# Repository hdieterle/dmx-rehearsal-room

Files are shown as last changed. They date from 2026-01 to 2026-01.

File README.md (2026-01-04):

# Rehearsal Room DMX Controller

A simple, standalone Arduino-based DMX lighting controller for rehearsal rooms with 20 predefined scenes.

## Features

- **Standalone Operation**: No PC required - works completely independently
- **Simple Controls**: Toggle switch for master on/off, two buttons for scene navigation
- **20 Preset Scenes**: Organized into working, mood, and show lighting categories
- **Smooth Transitions**: 1-second fade between scenes for professional look
- **Scene Memory**: Automatically remembers last scene after power cycle (EEPROM)
- **Visual Feedback**: 7-segment display shows current scene number
- **Multi-Device Support**: Controls moving heads, LED bars, and additional lighting

## Hardware Requirements

### Controller Components
- Arduino UNO R3 (or compatible)
- CTC-DRA-10-R2 DMX Shield (RS485-based)
- Adafruit 0.56" 4-Digit 7-Segment Display with I2C Backpack
- 1x Toggle Switch (Master On/Off)
- 2x Momentary Push Buttons (Scene navigation)

### DMX Fixtures
- 2x Fun Generation PicoBeam 30 Quad LED (moving heads, 13-channel mode)
- 3x Stairville LED Bar 120/4 RGB DMX (12-channel mode)
- 1x Botex MPX-4LED (dimmer channel for couch lamp)
- 1x Botex MPX-4LED (on/off channel for UV light)

## Installation

### 1. Hardware Setup

#### Arduino Pin Connections
| Component | Arduino Pin |
|---|---|
| Master On/Off Switch | D2 |
| Previous Scene Button | D3 |
| Next Scene Button | D4 |
| 7-Segment Display (I2C SDA) | A4 |
| 7-Segment Display (I2C SCL) | A5 |
| DMX Output (via Shield) | D0/D1 |

#### DMX Shield Jumper Settings (CTC-DRA-10-R2)
- **EN** (not ̅EN)
- **DE** (not Slave)
- **TX-uart** (not TX-io)

### 2. Software Installation

#### Required Libraries
Install these libraries via Arduino IDE Library Manager:
- `DMXSerial` by Matthias Hertel
- `Adafruit GFX Library`
- `Adafruit LED Backpack`
- `Wire` (included with Arduino IDE)
- `EEPROM` (included with Arduino IDE)

#### Upload the Sketch
1. Open `proberaum_dmx.ino` in Arduino IDE
2. Select **Board**: Arduino UNO
3. Select the correct **Port**
4. Click **Upload**

### 3. DMX Addressing

Configure your DMX fixtures with these start addresses:

| Fixture | DMX Start Address | Channels Used | Mode |
|---|---|---|---|
| PicoBeam #1 | 1 | 1-13 | 13ch |
| PicoBeam #2 | 14 | 14-26 | 13ch |
| LED Bar #1 | 27 | 27-38 | 12ch |
| LED Bar #2 | 39 | 39-50 | 12ch |
| LED Bar #3 | 51 | 51-62 | 12ch |
| Couch Lamp (Dimmer) | 63 | 63 | - |
| UV Light (On/Off) | 64 | 64 | - |

## Usage

### Basic Operation
1. **Power on** the Arduino controller
   - Controller automatically restores the last active scene from memory
2. Use the **Master Switch** to enable/disable all lights (displays "OFF" when disabled)
   - Turning off fades smoothly to blackout
3. Press **Next/Previous buttons** to cycle through scenes 0-19
   - Scenes fade smoothly over 1 second
   - Current scene is saved to memory automatically
4. The display shows the current scene number (e.g., "P.05" for scene 5)

### Scene Categories

#### Working Scenes (0-4)
- **0 - Blackout**: All lights off
- **1 - Work Light**: Bright white lighting for rehearsals
- **2 - Work Dim**: Dimmed white lighting
- **3 - Rehearsal Std**: Warm, cozy standard rehearsal lighting
- **4 - Rehearsal Focus**: Focused white spots with subtle ambience

#### Mood Scenes (5-9)
- **5 - Chill Blue**: Cool blue atmosphere with warm couch accent
- **6 - Warm Red**: Warm red/orange ambience
- **7 - Green Nature**: Natural green tones
- **8 - Purple Haze**: Purple/magenta mood
- **9 - UV Party**: UV blacklight with blue accents

#### Show Scenes (10-18)
- **10 - Show Split**: Red/blue color split
- **11 - Show Cyan Mag**: Cyan and magenta contrast
- **12 - Show Full White**: Maximum brightness white
- **13 - Show Strobe**: Subtle strobe effect
- **14 - Show Cross**: Crossed moving head positions
- **15 - Show Rainbow**: Rainbow colors across bars
- **16 - Show Yellow**: Bright yellow energy
- **17 - Show Wide**: Wide spread moving head positions
- **18 - Show Floor**: Downward-facing moving heads

#### Special Scenes
- **19 - Lounge**: Couch lamp only with subtle LED bar accents

## Customization

### Adding New Scenes
1. Open `proberaum_dmx.ino`
2. Increase `SCENE_COUNT` constant
3. Add a new scene entry to the `scenes[]` array
4. Upload the modified sketch

### Adjusting Pan/Tilt Values
Pan and tilt values depend on the physical mounting position of your moving heads:
- **Pan**: 0 = full left, 128 = center, 255 = full right (540° range)
- **Tilt**: 0 = up, 128 = horizontal, 255 = down (230° range)

Adjust these values in the scene definitions based on your room layout.

### Adding More DMX Fixtures
1. Update `TOTAL_CHANNELS` constant
2. Define new DMX start addresses
3. Create or extend data structures for the new fixtures
4. Modify `outputScene()` function to output to the new channels

## Technical Details

- **Memory**: Scenes stored in PROGMEM (Flash) to conserve RAM
- **Scene Transitions**: 1-second linear fade with 50 interpolation steps
  - Per-fixture fade control via boolean flags in scene definitions
  - UV light: instant snap (better visual effect)
  - Couch light: smooth fade
  - PicoBeams and LED bars: always fade
- **Scene Memory**: EEPROM-based persistence with magic number validation
- **Display Update**: Immediate when changing scenes
- **Button Debouncing**: 50ms debounce delay implemented
- **Fade Customization**: Adjustable via `FADE_DURATION_MS` and `FADE_STEPS` constants

## Known Limitations

- Fade transitions use linear interpolation (no easing curves)
- Scenes can only be modified by uploading new code (no runtime programming)
- LED Bar segment 4 has limited color control in 12-channel mode (R only, G/B missing)
- No MIDI input support
- EEPROM has ~100,000 write cycle limit (scene changes only, very long lifespan)

## Future Enhancements

Potential improvements for future versions:
- ✅ Soft fade transitions between scenes (implemented)
- ✅ EEPROM storage to remember last active scene (implemented)
- Easing curves for fades (ease-in/ease-out)
- Adjustable fade time via buttons
- Manual dimmer control via rotary encoder
- MIDI input for external control
- OLED display showing scene names instead of numbers

## Troubleshooting

### Display shows nothing
- Check I2C connections (SDA/SCL)
- Verify display address is 0x70
- Adjust brightness with `display.setBrightness()`

### No DMX output
- Verify DMX shield jumper settings
- Check DMX cable connections
- Ensure fixtures are powered and addressed correctly

### Buttons not responding
- Check pull-up resistor configuration
- Verify button wiring (should pull pin LOW when pressed)
- Test button continuity with multimeter

## Resources

- [DMXSerial Library Documentation](https://github.com/mathertel/DMXSerial)
- [PicoBeam 30 Manual](https://images.static-thomann.de/pics/atg/atgdata/document/manual/372682_c_372682_v3_en_online.pdf)
- [LED Bar 120/4 Manual](https://images.static-thomann.de/pics/atg/atgdata/document/manual/355287_c_355287_v2_de_online.pdf)
- [Open Fixture Library - PicoBeam](https://open-fixture-library.org/fun-generation/picobeam-30-quad-led)

## License

GNU General Public License v3.0 - See LICENSE file for details

## Contributing

This is a personal project for a specific rehearsal room setup. Feel free to fork and adapt it for your own needs.

## Author

Built for a basement rehearsal room with the goal of simple, reliable lighting control without requiring a computer.

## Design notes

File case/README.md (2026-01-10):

# DMX Controller Case - 3D Printing Files

Custom case design for the DMX Rehearsal Room Controller, optimized for the Prusa XL printer.

## Design Overview

**Case Style:** Two-part clamshell (top + bottom halves)
**Dimensions:** 180mm × 140mm × 50mm
**Wall Thickness:** 3mm
**Material:** Black filament recommended
**Print Settings:** 0.2mm layer height, 20% infill minimum

## Component Layout

### Bottom Half
- Arduino UNO R3 mounted internally with standoffs (no external access)
- DMX shield positioned side-by-side with Arduino (connected via jumper wires)
- 4× corner screw posts for case assembly

### Top Half - Front Panel
- USB-C panel mount connector (22mm hole, 28mm bezel)
- SS-22L05 DPDT slide switch (DMX/Programming mode selector)
- Labels: "USB", "DMX | PROG"

### Top Half - Rear Panel
- 2× Neutrik XLR-3 D-series connectors (24mm diameter, 24mm spacing)
  - Left: DMX OUT
  - Right: DMX THRU
- DC barrel jack (8mm hole) - 12V power input
- Labels: "DMX OUT", "DMX THRU", "12V DC"

### Top Half - Top Panel
- 7-segment display (50mm × 20mm rectangular cutout)
- Master toggle switch (DSQ14-R, 12mm hole)
- 2× Momentary buttons (DTQ14-S, 12mm holes)
  - PREV button
  - NEXT button
- Labels: "SCENE", "MASTER", "PREV", "NEXT"

## Files

- `dmx_controller_case.scad` - OpenSCAD source file (parametric, editable)
- `bottom_case.stl` - Bottom half STL (ready to print)
- `top_case.stl` - Top half STL (ready to print)

## How to Generate STL Files

### Method 1: Using OpenSCAD GUI (Recommended)

1. Download and install [OpenSCAD](https://openscad.org/downloads.html)
2. Open `dmx_controller_case.scad`
3. **To export bottom case:**
   - Ensure line 414 is uncommented: `bottom_case();`
   - Comment out lines 417-418 (top case)
   - Press F5 (Preview) or F6 (Render)
   - File → Export → Export as STL → Save as `bottom_case.stl`
4. **To export top case:**
   - Comment out line 414 (bottom case)
   - Uncomment lines 417-418:
     ```scad
     translate([0, case_width + 20, 0])
         top_case();
     ```
   - Press F5 (Preview) or F6 (Render)
   - File → Export → Export as STL → Save as `top_case.stl`

### Method 2: Using OpenSCAD Command Line

```bash
# Generate bottom case
openscad -o bottom_case.stl \
  -D 'RENDER_PART="bottom"' \
  dmx_controller_case.scad

# Generate top case
openscad -o top_case.stl \
  -D 'RENDER_PART="top"' \
  dmx_controller_case.scad
```

## Printing Instructions

### Prusa XL Settings
- **Filament:** Black PLA, PETG, or ABS
- **Layer Height:** 0.2mm (0.15mm for better text definition)
- **Infill:** 20% minimum (30% for more rigidity)
- **Supports:** None required (all overhangs < 45°)
- **Brim:** Optional (recommended for ABS to prevent warping)

### Print Orientation
- **Bottom case:** Print as-is (bottom facing build plate)
- **Top case:** Print upside-down (top panel facing build plate) for best surface finish on labels

### Post-Processing
- Debossed text labels can be filled with acrylic paint or paint markers for better contrast
- Use white or silver paint in debossed areas on black filament
- Wipe excess paint off surface immediately, leaving paint only in recesses

## Assembly Hardware Required

- 4× M3 × 20mm screws (corner posts, joining top and bottom halves)
- 4× M3 nuts or heat-set inserts (optional, for threaded corner posts)
- 4× M3 × 8mm screws (Arduino mounting to standoffs)
- 2× M2 × 8mm screws (SS-22L05 slide switch mounting)
- 4× M2.5 × 8mm screws (7-segment display mounting)
- Dupont jumper wires (Arduino to DMX shield connections: D0, D1, 5V, GND)

## Wiring Connections

### Arduino to DMX Shield (Side-by-Side Configuration)
| Arduino Pin | DMX Shield Pin | Wire Color Suggestion |
|---|---|---|
| D0 (RX) | D0 (RX) | Yellow |
| D1 (TX) | D1 (TX) | Orange |
| 5V | 5V | Red |
| GND | GND | Black |

### USB-C Extension Cable
- Connect internal USB-C plug to Arduino's USB-C port
- Route cable to front panel USB-C socket

### SS-22L05 Slide Switch Wiring
Wire the switch to disconnect D0/D1 during programming:
- **Position A (DMX mode):** Arduino D0/D1 connected to DMX shield
- **Position B (PROG mode):** Arduino D0/D1 disconnected from DMX shield

```
Arduino D0 ----[Switch Pole 1]---- DMX Shield D0
Arduino D1 ----[Switch Pole 2]---- DMX Shield D1
```

## Customization

The OpenSCAD file is fully parametric. You can easily adjust:
- Case dimensions (lines 9-11)
- Wall thickness (line 12)
- Component positions (lines 75-115)
- Label text (lines 361-407)
- Text depth (line 20)

After making changes, regenerate the STL files using the methods above.

## Troubleshooting

### Labels not visible
- Increase `text_depth` to 0.8mm or 1.0mm (line 20)
- Print with 0.15mm layer height for better detail
- Fill debossed text with white/silver paint

### Components don't fit
- Measure your actual components with calipers
- Update component dimensions in lines 22-73
- Regenerate STL files

### Case doesn't close properly
- Check for print warping (use brim for large flat parts)
- Verify wall thickness is exactly 3mm in slicer preview
- Sand down corner posts if too tight

## License

This case design is part of the DMX Rehearsal Room Controller project and is licensed under GPL-3.0.

## Resources

- [OpenSCAD Documentation](https://openscad.org/documentation.html)
- [Prusa XL Specifications](https://www.prusa3d.com/product/original-prusa-xl-2/)
- [Arduino UNO R3 Dimensions](https://docs.arduino.cc/hardware/uno-rev3)

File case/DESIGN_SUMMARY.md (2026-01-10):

# DMX Controller Case - Design Summary

## ✅ What's Been Created

All design files for your custom 3D-printable DMX controller case are ready!

### Files in `/case` directory:

1. **dmx_controller_case.scad** - OpenSCAD parametric design (fully editable)
2. **README.md** - Printing instructions and specifications
3. **ASSEMBLY.md** - Step-by-step assembly guide with wiring diagrams
4. **generate_stls.sh** - Helper script to generate STL files
5. **DESIGN_SUMMARY.md** - This file

## 📐 Case Specifications

| Parameter | Value |
|---|---|
| **Dimensions** | 180mm × 140mm × 50mm |
| **Wall Thickness** | 3mm |
| **Case Style** | Two-part clamshell (top + bottom) |
| **Material** | Black filament (PLA/PETG/ABS) |
| **Print Volume** | ~162,000 mm³ (fits Prusa XL easily) |
| **Estimated Print Time** | ~8-10 hours total (both halves) |
| **Assembly Hardware** | 4× M3 screws + nuts |

## 🔧 Component Layout

### Bottom Half
- Arduino UNO R3 mounted on internal standoffs
- DMX shield positioned side-by-side (connected via jumper wires)
- 4× corner screw posts for case assembly

### Top Half Panels

**Front Panel:**
- USB-C panel mount (22mm hole, 28mm bezel recess)
- SS-22L05 DPDT slide switch (DMX/PROG mode selector)
- Debossed labels: "USB", "DMX | PROG"

**Rear Panel:**
- 2× Neutrik XLR-3 connectors (24mm dia., D-series mounting)
- DC barrel jack (8mm hole, 2.1mm center-positive)
- Debossed labels: "DMX OUT", "DMX THRU", "12V DC"

**Top Panel:**
- 7-segment display (50mm × 20mm cutout)
- Master toggle switch (12mm hole)
- PREV button (12mm hole)
- NEXT button (12mm hole)
- Debossed labels: "SCENE", "MASTER", "PREV", "NEXT"

## 🖨️ How to Generate STL Files

### Option 1: OpenSCAD GUI (Easiest)

1. **Open OpenSCAD:**
   - Launch OpenSCAD from Applications folder
   - File → Open → Select `dmx_controller_case.scad`

2. **Export Bottom Case:**
   - Edit line 414: Ensure `bottom_case();` is uncommented
   - Comment out lines 417-418 (top case render)
   - Press **F6** (Render - this may take 1-2 minutes)
   - File → Export → Export as STL
   - Save as `bottom_case.stl`

3. **Export Top Case:**
   - Comment out line 414: `// bottom_case();`
   - Uncomment lines 417-418:
     ```scad
     translate([0, case_width + 20, 0])
         top_case();
     ```
   - Press **F6** (Render - this may take 1-2 minutes)
   - File → Export → Export as STL
   - Save as `top_case.stl`

### Option 2: Shell Script (If CLI works)

```bash
cd /Users/hdieterle/GitHub/dmx-rehearsal-room/case
chmod +x generate_stls.sh
./generate_stls.sh
```

*Note: OpenSCAD CLI may not work properly on macOS without Rosetta 2 or if running headless. Use GUI method if script fails.*

## 🎨 Customization Options

The design is fully parametric - you can easily adjust:

### Common Tweaks:
```scad
// Line 9-12: Case dimensions
case_length = 180;  // Make longer/shorter
case_width = 140;   // Make wider/narrower
case_height = 50;   // Make taller/shorter
wall_thickness = 3; // Make stronger/lighter

// Line 20: Label text depth
text_depth = 0.7;   // Deeper (0.8-1.0) for better visibility

// Lines 77-115: Component positions
// Adjust X/Y positions if components don't align
```

After editing, regenerate STL files.

## 🔌 Key Design Features

### ✅ Solved Problems:
1. **Arduino + Shield Side-by-Side:** Prevents XLR connector interference
2. **DMX/PROG Mode Switch:** No need to remove shield for programming
3. **USB-C Front Panel:** Easy programming access
4. **Integrated Labels:** No Dymo labels needed
5. **Desktop Stable:** No mounting holes, sits flat on table

### 🎯 Design Decisions:
- **3mm walls:** Good balance of strength and print time
- **Debossed text:** Better than embossed for black filament (paint-fillable)
- **No supports needed:** All overhangs < 45°
- **Screw posts in corners:** Easy assembly/disassembly
- **Component-specific cutouts:** Precise fit for all parts

## 📋 Next Steps

1. **Generate STL files** using OpenSCAD GUI (see above)
2. **Slice in PrusaSlicer:**
   - Import bottom_case.stl and top_case.stl
   - Use 0.2mm layer height, 20% infill
   - No supports needed
   - Consider 0.15mm layers for better label detail
3. **Print on Prusa XL** with black filament
4. **Post-process (optional):**
   - Fill debossed labels with white acrylic paint
   - Wipe excess from surface
   - Result: professional-looking white-on-black labels
5. **Assemble** following [ASSEMBLY.md](ASSEMBLY.md)

## 🛠️ If You Need Changes

The OpenSCAD file is designed for easy modifications:

### Want different labels?
→ Edit lines 361-407 in `dmx_controller_case.scad`

### Component doesn't fit?
→ Update dimensions in lines 22-73
→ Measure actual component with calipers
→ Regenerate STL

### Want different case size?
→ Change lines 9-11 (case_length, case_width, case_height)
→ Regenerate STL

### Want thicker walls?
→ Change line 12 (wall_thickness)
→ Regenerate STL

## 📚 Documentation Files

- **README.md** - Printing specs, hardware list, troubleshooting
- **ASSEMBLY.md** - Detailed assembly steps, wiring diagrams, safety notes
- **CLAUDE.md** - (in parent dir) Technical project documentation

## 🎉 Design Complete!

All files are ready. You now have:
- ✅ Parametric OpenSCAD design
- ✅ Component specifications
- ✅ Printing instructions
- ✅ Assembly guide
- ✅ Wiring diagrams
- ✅ Helper scripts

**Total Design Time:** ~2 hours
**Estimated Print Time:** ~8-10 hours
**Estimated Assembly Time:** ~2-3 hours

---

## 💡 Tips

1. **First print?** Start with bottom case only to test fit
2. **Labels hard to read?** Increase text_depth to 0.8mm or paint them white
3. **Case won't close?** Check for print warping, sand corner posts if needed
4. **Components loose?** Add small pieces of foam tape for snug fit
5. **Want ventilation?** Add small holes in bottom case (edit line ~125)

## 📞 Support

If you need design modifications or have questions:
- Check [README.md](README.md) for printing FAQs
- Check [ASSEMBLY.md](ASSEMBLY.md) for assembly help
- Review OpenSCAD comments for parameter explanations
- Test fit components before final assembly

**Enjoy your custom DMX controller case!** 🎵💡

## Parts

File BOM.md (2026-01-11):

# Bill of Materials (BOM)

Complete parts list for building the DMX Rehearsal Room Controller.

## Electronics

| Qty | Component | Description | Notes |
|-----|---|---|---|
| 1 | Arduino UNO R3 | Microcontroller board | Official or compatible clone |
| 1 | CTC-DRA-10-R2 DMX Shield | RS485-based DMX interface | - |
| 1 | Adafruit 0.56" 4-Digit 7-Segment Display | Yellow, with I2C backpack | Part #: 878 or 879 |
| 1 | USB-C Panel Mount Extension Cable | 22mm hole, 28mm bezel | Male-to-female, ~30cm cable length |
| 1 | SS-22L05 DPDT Slide Switch | DMX/Programming mode selector | 6-pin, through-hole mounting |
| 1 | DSQ14-R Toggle Switch | Master On/Off, 12mm mounting hole | SPST or SPDT |
| 2 | DTQ14-S Momentary Push Buttons | Preset Prev/Next, 12mm mounting hole | Normally open (NO) |
| 2 | Neutrik XLR-3 D-Series Panel Mount | 24mm mounting hole | NC3FD-LX (female) or similar |
| 1 | DC Barrel Jack Panel Mount | 2.1mm center-positive, 8mm mounting hole | 9-12V input |
| 1 | 12V DC Power Supply | Center-positive, 2.1mm barrel plug | Minimum 1A, recommend 2A+ |
| 1 | USB-A to USB-B Cable | For Arduino programming | ~1-2m length recommended |

## Wiring & Connectors

| Qty | Component | Description | Notes |
|-----|---|---|---|
| 1 | Dupont Jumper Wire Set | Male-to-female, 10-15cm length | For Arduino-to-shield connections |
| 1m | 22-24 AWG Stranded Wire | Assorted colors | For switch wiring |
| 1m | Heat Shrink Tubing | Assorted sizes | For wire insulation |

## Hardware (Case Assembly)

| Qty | Component | Description | Notes |
|-----|---|---|---|
| 4 | M3 × 20mm Screws | Corner posts (case assembly) | Phillips or socket head |
| 4 | M3 Nuts | For corner posts | Or use heat-set inserts |
| 4 | M3 × 8mm Screws | Arduino mounting | Phillips |
| 2 | M2 × 8mm Screws | Slide switch mounting | Phillips |
| 2 | M2 Nuts | Slide switch mounting | - |
| 4 | M2.5 × 8mm Screws | Display mounting | Phillips |

## 3D Printing Materials

| Qty | Component | Description | Notes |
|-----|---|---|---|
| ~200g | Black Filament | PLA, PETG, or ABS | For bottom case |
| ~100g | Black Filament | PLA, PETG, or ABS | For top case (lid) |

**Print Settings:**
- Layer height: 0.2mm (or 0.15mm for better label detail)
- Infill: 20% minimum (30% recommended)
- Supports: None required
- Estimated print time: 8-10 hours total

## Optional Components

| Qty | Component | Description | Notes |
|-----|---|---|---|
| 1 | White Acrylic Paint | For filling debossed labels | Optional, improves label visibility |
| 4 | M3 Heat-Set Inserts | Alternative to M3 nuts | For cleaner assembly |
| 1 | Cable Management Kit | Zip ties, adhesive mounts | For internal wire routing |

## DMX Fixtures (Not Included)

The controller is designed for the following DMX fixtures (not included in this BOM):

| Qty | Fixture | Start Address | Channels |
|-----|---|---|---|
| 2 | Fun Generation PicoBeam 30 Quad LED | 1, 14 | 13ch each (26ch total) |
| 3 | Stairville LED Bar 120/4 RGB DMX | 27, 39, 51 | 12ch each (36ch total) |
| 1 | Botex MPX-4LED (Channel 1) | 63 | 1ch (dimmer) |
| 1 | Botex MPX-4LED (Channel 2) | 64 | 1ch (on/off) |

**Total DMX Channels Used:** 64

## Tools Required

### Soldering
- Soldering iron (for switch wiring)
- Solder (60/40 rosin core)
- Wire strippers
- Flush cutters
- Helping hands or PCB holder

### Assembly
- Phillips screwdrivers (various sizes)
- Small flathead screwdriver
- Multimeter (for continuity testing)
- Calipers (optional, for measuring components)

### 3D Printing
- 3D printer (Prusa XL or similar, min. 180×140×60mm build volume)
- Slicer software (PrusaSlicer recommended)

### Optional
- Heat-set insert tool (soldering iron with tip works)
- Deburring tool (for cleaning print edges)
- Small paintbrush (for filling labels)

## Estimated Total Cost

| Category | Estimated Cost (EUR) |
|---|---|
| Electronics | €80-120 |
| Wiring & Connectors | €10-15 |
| Hardware | €5-10 |
| 3D Printing Materials | €10-15 |
| **Total** | **€105-160** |

*Prices are approximate and may vary by supplier and region.*

## Recommended Suppliers

### Europe
- **Electronics:** Reichelt, Conrad, Mouser, DigiKey
- **DMX Components:** Thomann, Musicstore
- **Hardware:** Würth, local hardware store
- **3D Printing:** Prusa3D filament, local suppliers

### General
- **Arduino/Electronics:** Amazon, AliExpress (clones)
- **Adafruit Products:** Adafruit.com, authorized distributors
- **Neutrik Connectors:** Thomann, official Neutrik distributors

## Notes

1. **Arduino Clones:** Compatible Arduino UNO R3 clones work fine and are significantly cheaper than official boards.

2. **Switch Compatibility:** The DSQ14-R and DTQ14-S switch part numbers may vary by supplier. Look for 12mm mounting hole toggle/momentary switches.

3. **Power Supply:** Ensure the power supply is center-positive and rated for at least 1A. The Arduino draws ~50-100mA, plus any connected fixtures draw power from their own supplies.

4. **XLR Connectors:** The Neutrik D-series (NC3FD-LX) are panel-mount female XLR connectors. The "D" designation refers to the D-shaped mounting flange.

5. **Filament Color:** Black filament is recommended for debossed labels. The labels can optionally be filled with white acrylic paint for better contrast.

6. **Heat-Set Inserts:** If using heat-set inserts instead of M3 nuts, use M3×5.7mm (OD) inserts designed for 3D printing.

## Assembly Instructions

Refer to [case/ASSEMBLY.md](case/ASSEMBLY.md) for detailed step-by-step assembly instructions.

## Design Files

- OpenSCAD source: [case/dmx_controller_case.scad](case/dmx_controller_case.scad)
- Arduino sketch: [proberaum_dmx/proberaum_dmx.ino](proberaum_dmx/proberaum_dmx.ino)
- Printing guide: [case/README.md](case/README.md)

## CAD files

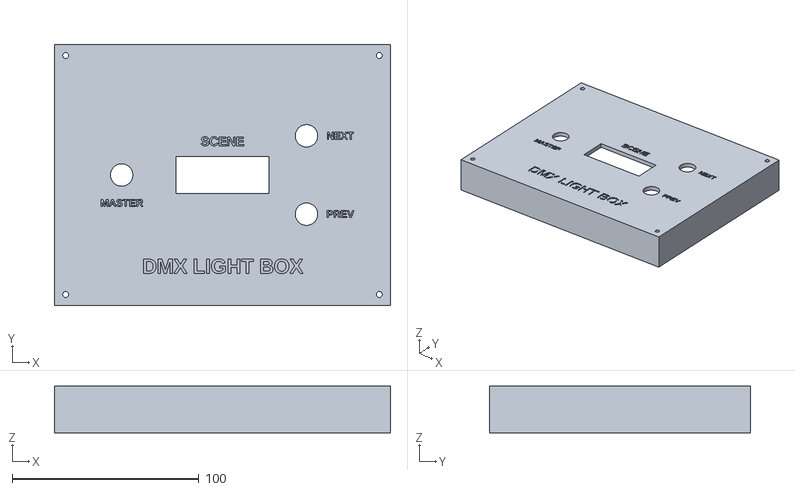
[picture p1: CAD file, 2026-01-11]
case/dmx_controller_case_top.stl
180.0 x 140.0 x 25.0

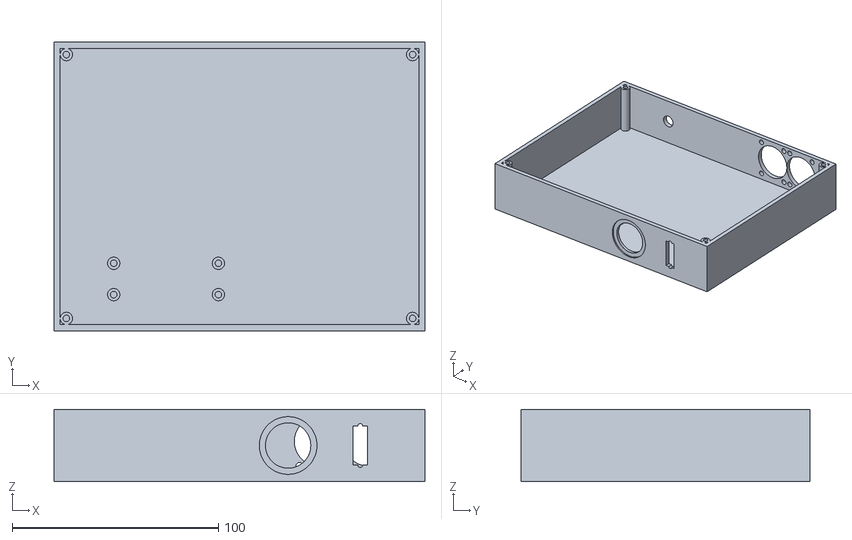
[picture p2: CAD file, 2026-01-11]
case/dmx_controller_case_bottom.stl
180.0 x 140.0 x 35.0

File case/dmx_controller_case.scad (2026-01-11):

// DMX Rehearsal Room Controller Case
// Two-part clamshell design for Prusa XL
// All dimensions in millimeters

// ========== GLOBAL PARAMETERS ==========
$fn = 60; // Circle resolution (higher = smoother, slower render)

// Case dimensions
case_length = 180;  // X direction (front to back)
case_width = 140;   // Y direction (left to right)
case_height = 60;   // Z direction (total height - increased for better proportions)
case_bottom_height = 35;  // Height of bottom case (contains all connectors)
case_top_height = 25;     // Height of top case (lid)
wall_thickness = 3; // Wall thickness

// Screw posts for case assembly
screw_post_diameter = 6;
screw_hole_diameter = 3.2; // M3 screw clearance
screw_post_count = 4; // Corner posts

// Label text depth
text_depth = 0.7; // Debossed text for black filament

// ========== COMPONENT DIMENSIONS ==========

// Arduino UNO R3
arduino_length = 68.6;
arduino_width = 53.3;
arduino_hole_spacing_length = 50.8;
arduino_hole_spacing_width = 15.2;
arduino_hole_offset_x = 13.97;
arduino_hole_offset_y = 2.54;
arduino_mount_hole = 3.2; // M3 clearance
arduino_standoff_height = 8; // Height above case bottom

// DMX Shield (approximate based on XLR positions)
shield_length = 70;
shield_width = 60;
shield_standoff_height = 8;

// XLR Connectors (Neutrik D-series)
xlr_diameter = 24;
xlr_spacing = 24; // Center to center
xlr_screw_spacing = 19; // Horizontal screw spacing
xlr_screw_vertical = 24; // Vertical position from center
xlr_screw_hole = 3.5; // Mounting screw size

// USB-C Panel Mount
usbc_hole_diameter = 22;
usbc_bezel_diameter = 28;
usbc_bezel_depth = 1.5;

// SS-22L05 DPDT Slide Switch
slide_switch_width = 19;
slide_switch_height = 6.9;
slide_switch_slot_length = 5;
slide_switch_slot_width = 2.5;
slide_switch_screw_spacing = 19; // Horizontal M2 screw spacing
slide_switch_screw_hole = 2.3; // M2 clearance

// Toggle Switch (DSQ14-R)
toggle_hole_diameter = 12;

// Momentary Buttons (DTQ14-S)
button_hole_diameter = 12;

// 7-Segment Display (Adafruit 0.56" 4-digit)
display_width = 50;
display_height = 20;
display_screw_spacing_x = 45; // Approximate
display_screw_spacing_y = 15; // Approximate
display_screw_hole = 2.5; // M2.5 or small screw

// DC Barrel Jack
dc_jack_hole_diameter = 8;

// ========== COMPONENT POSITIONS ==========

// Arduino position (bottom left area)
arduino_pos_x = 15;
arduino_pos_y = 15;

// DMX Shield position (bottom right area, side-by-side with Arduino)
shield_pos_x = arduino_pos_x + arduino_length + 20; // 20mm gap for wiring
shield_pos_y = 15;

// Front panel components (front = Y=0 end)
// USB and switch positioned above DMX shield (right side)
usbc_pos_x = shield_pos_x + 10;  // Positioned above shield (~113mm from left)
usbc_pos_y = 0;
usbc_pos_z = case_bottom_height / 2;  // Centered in bottom case wall (17.5mm)

slide_switch_pos_x = shield_pos_x + 45;  // Positioned right of USB (~148mm from left)
slide_switch_pos_y = 0;
slide_switch_pos_z = case_bottom_height / 2;  // Centered in bottom case wall (17.5mm)

// Rear panel components (rear = Y=case_width end)
// XLRs positioned above the DMX shield (right side of case)
xlr_pos_x = shield_pos_x + 25;  // Positioned above shield (~129mm from left)
xlr_pos_y = case_width;
xlr_pos_z = case_bottom_height / 2 + 2;  // Raised 2mm higher (19.5mm) for shield solder bumps
xlr_left_offset_x = 0;
xlr_right_offset_x = xlr_spacing;

dc_jack_pos_x = arduino_pos_x + 25;  // Positioned above Arduino (~40mm from left)
dc_jack_pos_y = case_width;
dc_jack_pos_z = case_bottom_height / 2 + 2;  // Raised 2mm higher (19.5mm) to match XLRs

// Top panel components
display_pos_x = case_length * 0.5;
display_pos_y = case_width * 0.5;

toggle_pos_x = case_length * 0.2;
toggle_pos_y = case_width * 0.5;

button_prev_pos_x = case_length * 0.75;
button_prev_pos_y = case_width * 0.35;

button_next_pos_x = case_length * 0.75;
button_next_pos_y = case_width * 0.65;

// ========== MODULES ==========

// Bottom case half
module bottom_case() {
    difference() {
        // Main shell
        union() {
            // Bottom plate
            cube([case_length, case_width, wall_thickness]);

            // Walls (bottom case)
            translate([0, 0, 0])
                cube([wall_thickness, case_width, case_bottom_height]);
            translate([case_length - wall_thickness, 0, 0])
                cube([wall_thickness, case_width, case_bottom_height]);
            translate([0, 0, 0])
                cube([case_length, wall_thickness, case_bottom_height]);
            translate([0, case_width - wall_thickness, 0])
                cube([case_length, wall_thickness, case_bottom_height]);

            // Corner screw posts
            create_corner_posts();

            // Arduino mounting posts
            create_arduino_posts();

            // DMX Shield mounting posts (will screw into XLR connectors)
            // (Not needed as XLRs mount to rear panel)
        }

        // Screw holes in corner posts (threaded from top)
        corner_post_positions() {
            translate([0, 0, -1])
                cylinder(h=case_bottom_height + 2, d=screw_hole_diameter);
        }

        // Front panel cutouts (Y=0 wall) - all in bottom case
        translate([usbc_pos_x, usbc_pos_y, usbc_pos_z])
            rotate([90, 0, 0])
                usbc_cutout();

        translate([slide_switch_pos_x, slide_switch_pos_y, slide_switch_pos_z])
            rotate([90, 0, 0])
                slide_switch_cutout();

        // Rear panel cutouts (Y=case_width wall) - bottom half
        translate([xlr_pos_x + xlr_left_offset_x, xlr_pos_y, xlr_pos_z])
            rotate([90, 0, 0])
                xlr_cutout();

        translate([xlr_pos_x + xlr_right_offset_x, xlr_pos_y, xlr_pos_z])
            rotate([90, 0, 0])
                xlr_cutout();

        translate([dc_jack_pos_x, dc_jack_pos_y, dc_jack_pos_z])
            rotate([90, 0, 0])
                translate([0, 0, -wall_thickness - 1])
                    cylinder(h=wall_thickness + 4, d=dc_jack_hole_diameter);

        // Front/Rear panel labels (debossed text on bottom case)
        labels_bottom_case();
    }
}

// Top case half (lid)
module top_case() {
    difference() {
        // Main shell
        union() {
            // Top plate
            translate([0, 0, case_top_height - wall_thickness])
                cube([case_length, case_width, wall_thickness]);

            // Walls (top case - shorter, acts as lid)
            translate([0, 0, 0])
                cube([wall_thickness, case_width, case_top_height]);
            translate([case_length - wall_thickness, 0, 0])
                cube([wall_thickness, case_width, case_top_height]);
            translate([0, 0, 0])
                cube([case_length, wall_thickness, case_top_height]);
            translate([0, case_width - wall_thickness, 0])
                cube([case_length, wall_thickness, case_top_height]);

            // Corner screw posts (top case)
            create_corner_posts_top();
        }

        // Top panel cutouts
        translate([display_pos_x, display_pos_y, case_top_height - wall_thickness - 1])
            display_cutout();

        translate([toggle_pos_x, toggle_pos_y, case_top_height - wall_thickness - 1])
            cylinder(h=wall_thickness + 2, d=toggle_hole_diameter);

        translate([button_prev_pos_x, button_prev_pos_y, case_top_height - wall_thickness - 1])
            cylinder(h=wall_thickness + 2, d=button_hole_diameter);

        translate([button_next_pos_x, button_next_pos_y, case_top_height - wall_thickness - 1])
            cylinder(h=wall_thickness + 2, d=button_hole_diameter);

        // Screw holes in corner posts (clearance from bottom)
        corner_post_positions() {
            translate([0, 0, -1])
                cylinder(h=case_top_height + 2, d=screw_hole_diameter);
        }

        // Labels (debossed text)
        labels();
    }
}

// Corner screw post positions and creation
module corner_post_positions() {
    offset = screw_post_diameter / 2 + wall_thickness;

    for (pos = [
        [offset, offset, wall_thickness],
        [case_length - offset, offset, wall_thickness],
        [offset, case_width - offset, wall_thickness],
        [case_length - offset, case_width - offset, wall_thickness]
    ]) {
        translate(pos)
            children();
    }
}

// Create corner screw posts for bottom case
module create_corner_posts_bottom() {
    corner_post_positions()
        cylinder(h=case_bottom_height - wall_thickness, d=screw_post_diameter);
}

// Create corner screw posts for top case
module create_corner_posts_top() {
    corner_post_positions()
        cylinder(h=case_top_height - wall_thickness, d=screw_post_diameter);
}

// Compatibility wrapper - defaults to bottom
module create_corner_posts() {
    create_corner_posts_bottom();
}
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

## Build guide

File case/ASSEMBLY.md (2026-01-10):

# DMX Controller Case - Assembly Guide

Step-by-step instructions for assembling your custom DMX controller case.

## Required Components

### Electronics
- [x] Arduino UNO R3
- [x] CTC-DRA-10-R2 DMX Shield
- [x] Adafruit 0.56" 4-Digit 7-Segment Display (yellow, with I2C backpack)
- [x] USB-C panel mount extension cable
- [x] SS-22L05 DPDT slide switch (programming mode selector)
- [x] DSQ14-R toggle switch (Master On/Off)
- [x] 2× DTQ14-S momentary push buttons (Preset Prev/Next)
- [x] 2× Neutrik XLR-3 D-series panel mount connectors
- [x] DC barrel jack panel mount (2.1mm, 8mm mounting hole)
- [x] Dupont jumper wires (male-to-female, 10-15cm length)

### Hardware
- [x] 4× M3 × 20mm screws (case assembly)
- [x] 4× M3 nuts or heat-set inserts
- [x] 4× M3 × 8mm screws (Arduino mounting)
- [x] 2× M2 × 8mm screws + nuts (slide switch)
- [x] 4× M2.5 × 8mm screws (display mounting)
- [x] Wire (22-24 AWG) for switch wiring
- [x] Heat shrink tubing

### Tools
- Soldering iron (for switch wiring)
- Wire strippers
- Screwdriver set (Phillips, flathead)
- Flush cutters
- Multimeter (for continuity testing)
- Heat-set insert tool (optional, if using inserts)

## Pre-Assembly: Print the Case

1. **Print both halves:**
   - Open `dmx_controller_case.scad` in OpenSCAD
   - Follow instructions in `README.md` to export `bottom_case.stl` and `top_case.stl`
   - Print on Prusa XL with black filament
   - Settings: 0.2mm layer height, 20%+ infill

2. **Post-process (optional):**
   - Fill debossed labels with white acrylic paint
   - Let dry, then wipe excess from surface
   - Result: white text on black background

## Step 1: Mount Arduino to Bottom Case

1. Place Arduino UNO in bottom case (left side, near front-left corner)
2. Align Arduino mounting holes with standoffs
3. Insert 4× M3 × 8mm screws through Arduino holes into standoffs
4. Tighten screws (don't overtighten, PCB can crack)

**Position:** Arduino should be ~15mm from left wall, ~15mm from front wall

## Step 2: Wire the SS-22L05 Slide Switch (DMX/PROG Mode Selector)

This switch disconnects D0/D1 from the DMX shield during programming.

### Wiring Diagram

```
                       SS-22L05 DPDT Slide Switch
                       (View from solder side)

    Common Pole 1 ----o   o---- NO Contact 1
    Common Pole 2 ----o   o---- NO Contact 2

DMX Mode (Position A):
  Arduino D0 → Common Pole 1 → NO Contact 1 → DMX Shield D0
  Arduino D1 → Common Pole 2 → NO Contact 2 → DMX Shield D1

PROG Mode (Position B):
  Arduino D0 → Common Pole 1 (disconnected)
  Arduino D1 → Common Pole 2 (disconnected)
  DMX Shield D0/D1 → floating (disconnected)
```

### Steps

1. **Cut 4 wires** (~8-10cm each):
   - 2× Orange (for D1 connections)
   - 2× Yellow (for D0 connections)

2. **Solder to switch:**
   - Common Pole 1: Yellow wire to Arduino D0
   - Common Pole 2: Orange wire to Arduino D1
   - NO Contact 1: Yellow wire to DMX Shield D0
   - NO Contact 2: Orange wire to DMX Shield D1

3. **Add heat shrink** to each solder joint

4. **Test with multimeter:**
   - Position A (DMX): Continuity between Arduino D0/D1 and Shield D0/D1
   - Position B (PROG): No continuity

## Step 3: Position DMX Shield

1. Place DMX shield in bottom case (right side, side-by-side with Arduino)
2. Shield will be secured by XLR connectors mounting to rear panel
3. **Do not stack** shield on Arduino (causes XLR connector clearance issues)

**Position:** Shield should be ~103mm from left wall (~20mm gap after Arduino), ~15mm from front wall

## Step 4: Wire Arduino to DMX Shield

Use Dupont jumper wires to connect (remember: D0/D1 go through the slide switch):

| Connection | Wire | Notes |
|---|---|---|
| Arduino 5V → Shield 5V | Red jumper | Direct connection |
| Arduino GND → Shield GND | Black jumper | Direct connection |
| Arduino D0 → Switch Pole 1 | Yellow (from Step 2) | Via slide switch |
| Switch NO1 → Shield D0 | Yellow (from Step 2) | Via slide switch |
| Arduino D1 → Switch Pole 2 | Orange (from Step 2) | Via slide switch |
| Switch NO2 → Shield D1 | Orange (from Step 2) | Via slide switch |

## Step 5: Mount Rear Panel Components

### XLR Connectors (2× Neutrik D-series)
1. Insert left XLR through rear panel hole (labeled "DMX OUT")
2. Insert right XLR through rear panel hole (labeled "DMX THRU")
3. Secure each with 4× mounting screws (included with Neutrik connectors)
4. **This secures the DMX shield in place**

### DC Barrel Jack
1. Insert DC jack through rear panel 8mm hole
2. Secure with included nut or mounting screws
3. Wire DC jack to Arduino Vin and GND:
   - Center pin (+) → Arduino Vin
   - Outer sleeve (-) → Arduino GND

## Step 6: Mount Front Panel Components

### USB-C Panel Mount
1. Feed USB-C extension cable through case from inside
2. Insert panel mount socket through front panel 22mm hole
3. Socket bezel should sit flush in recess
4. Connect internal USB-C plug to Arduino's USB-C port

### SS-22L05 Slide Switch
1. Insert switch through front panel rectangular cutout
2. Align mounting holes
3. Secure with 2× M2 × 8mm screws and nuts from inside
4. Verify slider moves freely between DMX and PROG positions
5. Label positions with marker if needed

## Step 7: Mount Top Panel Components

### 7-Segment Display
1. Insert display through 50mm × 20mm rectangular cutout from inside
2. Display should be visible from top, PCB on inside
3. Secure with 4× M2.5 × 8mm screws around display corners
4. Connect display I2C cable to Arduino:
   - VCC → Arduino 5V
   - GND → Arduino GND
   - SDA → Arduino A4
   - SCL → Arduino A5

### Master Toggle Switch (DSQ14-R)
1. Insert switch through 12mm hole (labeled "MASTER")
2. Secure with included nut
3. Wire switch to Arduino D2:
   - One terminal → Arduino D2
   - Other terminal → Arduino GND

### Momentary Buttons (2× DTQ14-S)
1. **PREV button:** Insert through left 12mm hole (labeled "PREV")
2. **NEXT button:** Insert through right 12mm hole (labeled "NEXT")
3. Secure each with included nuts
4. Wire buttons to Arduino:
   - PREV: One terminal → Arduino D3, other → GND
   - NEXT: One terminal → Arduino D4, other → GND

## Step 8: Final Assembly

1. **Test before closing:**
   - Set slide switch to PROG position
   - Connect USB cable to front panel USB-C socket
   - Upload sketch from [proberaum_dmx.ino](../proberaum_dmx/proberaum_dmx.ino)
   - Verify upload succeeds
   - Set slide switch to DMX position
   - Power via DC jack (9-12V)
   - Test all buttons, display, and master switch

2. **Close the case:**
   - Carefully align top and bottom halves
   - Ensure no wires are pinched
   - Insert 4× M3 × 20mm screws through corner posts
   - Tighten screws evenly (diagonal pattern)

3. **Final check:**
   - All labels visible and readable
   - Slide switch moves freely
   - Display shows scene number
   - Buttons respond correctly
   - DMX output working (test with DMX fixture)

## Wiring Color Code Reference

| Connection | Recommended Wire Color |
|---|---|
| +5V / VCC  | Red |
| GND | Black |
| D0 (RX) | Yellow |
| D1 (TX) | Orange |
| D2 (Master)| Blue |
| D3 (Prev)  | Green |
| D4 (Next)  | Purple |
| A4 (SDA) | White |
| A5 (SCL) | Brown |

## Troubleshooting

### Arduino won't program
- **Check:** Slide switch in PROG position?
- **Check:** USB-C cable properly connected?
- **Check:** Arduino visible in Arduino IDE (Tools → Port)?

### Display not working
- **Check:** I2C address (default 0x70, check code)
- **Check:** SDA/SCL connections (A4/A5)
- **Check:** Display power (5V/GND)

### Buttons not responding
- **Check:** Button wiring (one side to Arduino pin, other to GND)
- **Check:** Code pullup resistors enabled (`pinMode(pin, INPUT_PULLUP)`)

### DMX not outputting
- **Check:** Slide switch in DMX position
- **Check:** D0/D1 wired correctly through switch
- **Check:** Shield jumpers set correctly (EN, DE, TX-uart)

### Case won't close
- **Check:** Wires not bunched up or pinched
- **Check:** Arduino seated flat on standoffs
- **Check:** No component interference

## Maintenance

- **Switch cleaning:** Spray contact cleaner into slide switch yearly
- **Display brightness:** Adjustable in code (`display.setBrightness(15)`)
- **Firmware updates:** Set switch to PROG, connect USB, upload new code

## Safety Notes

⚠️ **Important:**
- Always disconnect power before opening case
- Use 9-12V DC power only (center positive)
- Don't exceed 12V (Arduino damage risk)
- Ensure XLR connectors are properly wired (pin 1=GND, 2=Data-, 3=Data+)
- Keep case dry (not waterproof)

## Done!

Your DMX controller is now assembled and ready for use in the rehearsal room. Enjoy the smooth scene transitions! 🎵💡

---

**Next Steps:**
- Read [README.md](../README.md) for usage instructions
- Explore scene customization in [proberaum_dmx.ino](../proberaum_dmx/proberaum_dmx.ino)
- Check [CLAUDE.md](../CLAUDE.md) for technical details

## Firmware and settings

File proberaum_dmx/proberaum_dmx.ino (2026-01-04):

/*
 * Rehearsal Room DMX Controller
 *
 * Hardware:
 * - Arduino UNO
 * - CTC-DRA-10-R2 DMX Shield
 * - Toggle switch on Pin 2 (Master On/Off)
 * - Button on Pin 3 (Previous preset)
 * - Button on Pin 4 (Next preset)
 *
 * DMX Devices:
 * - Channel 1-13:  PicoBeam 1 (13ch mode)
 * - Channel 14-26: PicoBeam 2 (13ch mode)
 * - Channel 27-38: LED Bar 1 (12ch mode)
 * - Channel 39-50: LED Bar 2 (12ch mode)
 * - Channel 51-62: LED Bar 3 (12ch mode)
 * - Channel 63:    Botex Dimmer (Couch hanging lamp)
 * - Channel 64:    Botex UV light (On/Off)
 *
 * Jumper Settings CTC-DRA-10-R2:
 * - EN (not ̅EN)
 * - DE (not Slave)
 * - TX-uart (not TX-io)
 */

#include <DMXSerial.h>
#include <Wire.h>
#include <Adafruit_GFX.h>
#include <Adafruit_LEDBackpack.h>
#include <EEPROM.h>

Adafruit_7segment display = Adafruit_7segment();

// === PIN DEFINITIONS ===
const byte PIN_MASTER = 2;    // Toggle switch Master On/Off
const byte PIN_PREV = 3;      // Button previous preset
const byte PIN_NEXT = 4;      // Button next preset

// === DMX ADDRESSES ===
const byte PICO1_START = 1;
const byte PICO2_START = 14;
const byte BAR1_START = 27;
const byte BAR2_START = 39;
const byte BAR3_START = 51;
const byte BOTEX_COUCH = 63;
const byte BOTEX_UV = 64;

const byte TOTAL_CHANNELS = 64;

// === FADE SETTINGS ===
const unsigned int FADE_DURATION_MS = 1000;  // 1 second fade time
const byte FADE_STEPS = 50;                   // Number of fade steps
const unsigned int FADE_STEP_DELAY = FADE_DURATION_MS / FADE_STEPS;

// === EEPROM SETTINGS ===
const int EEPROM_ADDR_SCENE = 0;      // Address to store current scene
const int EEPROM_ADDR_MAGIC = 1;      // Address to store magic number
const byte EEPROM_MAGIC = 0xA5;       // Magic number to verify valid EEPROM data

// === PicoBeam 13-Channel Offsets ===
// 0: Pan, 1: Pan Fine, 2: Tilt, 3: Tilt Fine, 4: Speed,
// 5: Dimmer, 6: Strobe, 7: Red, 8: Green, 9: Blue, 10: White,
// 11: Program, 12: Program Speed
enum PicoChannel {
  PICO_PAN = 0,
  PICO_PAN_FINE = 1,
  PICO_TILT = 2,
  PICO_TILT_FINE = 3,
  PICO_SPEED = 4,
  PICO_DIMMER = 5,
  PICO_STROBE = 6,
  PICO_RED = 7,
  PICO_GREEN = 8,
  PICO_BLUE = 9,
  PICO_WHITE = 10,
  PICO_PROGRAM = 11,
  PICO_PROG_SPEED = 12
};

// === LED Bar 12-Channel Offsets ===
// 0: Dimmer, 1: Strobe, 2: Red1, 3: Green1, 4: Blue1,
// 5: Red2, 6: Green2, 7: Blue2, 8: Red3, 9: Green3, 10: Blue3,
// 11: Red4, 12: Green4, 13: Blue4 -- WAIT that's 14!
// Actually 12ch: Dimmer, Strobe, then 4 segments RGB?
// I'll use the simple 3-channel RGB mode data:
// According to manual: 12ch = segment control
// Simplified: 0: Dimmer, 1: Strobe, 2-4: Seg1 RGB, 5-7: Seg2, 8-10: Seg3, 11: Macro
// For simplicity we use all segments the same

enum BarChannel {
  BAR_DIMMER = 0,
  BAR_STROBE = 1,
  BAR_SEG1_R = 2,
  BAR_SEG1_G = 3,
  BAR_SEG1_B = 4,
  BAR_SEG2_R = 5,
  BAR_SEG2_G = 6,
  BAR_SEG2_B = 7,
  BAR_SEG3_R = 8,
  BAR_SEG3_G = 9,
  BAR_SEG3_B = 10,
  BAR_SEG4_R = 11  // Only R in 12-channel, G and B missing
  // Note: 12ch mode only has 12 channels, Seg4 is incomplete
  // We still use all 12 and set Seg4 to R only
};

// === SCENES ===
const byte SCENE_COUNT = 20;
byte currentScene = 0;
byte previousScene = 0;
bool masterOn = false;

// Scene data: Compact structure per scene
// Each scene defines all relevant values

struct PicoBeamState {
  byte pan;
  byte tilt;
  byte speed;
  byte dimmer;
  byte strobe;
  byte red;
  byte green;
  byte blue;
  byte white;
};

struct LedBarState {
  byte dimmer;
  byte red;
  byte green;
  byte blue;
};

struct Scene {
  const char* name;
  PicoBeamState pico1;
  PicoBeamState pico2;
  LedBarState bar1;
  LedBarState bar2;
  LedBarState bar3;
  byte couchLight;      // Botex Dimmer hanging lamp 0-255
  bool couchFade;       // Should couch light fade?
  byte uvLight;         // Botex UV 0 or 255
  bool uvFade;          // Should UV light fade?
};

// Helper macros for readable scene definitions
#define PICO_OFF        {128, 128, 0, 0, 0, 0, 0, 0, 0}
#define PICO_CENTER_OFF {128, 128, 0, 0, 0, 0, 0, 0, 0}
#define BAR_OFF         {0, 0, 0, 0}

// Pan: 0=left, 128=center, 255=right (540° range)
// Tilt: 0=up, 128=center, 255=down (230° range)

const Scene scenes[SCENE_COUNT] PROGMEM = {
  // === WORKING SCENES ===

  // 0: Blackout
  {
    "Blackout",
    PICO_OFF, PICO_OFF,
    BAR_OFF, BAR_OFF, BAR_OFF,
    0, true,   // couchLight, couchFade
    0, false   // uvLight, uvFade
  },

  // 1: Work light (Bars white, couch lamp on)
  {
    "Work Light",
    {128, 128, 0, 180, 0, 200, 200, 200, 255},
    {128, 128, 0, 180, 0, 200, 200, 200, 255},
    {255, 255, 255, 255},
    {255, 255, 255, 255},
    {255, 255, 255, 255},
    200, true,
    0, false
  },

  // 2: Work light dimmed
  {
    "Work Dim",
    {128, 128, 0, 100, 0, 180, 180, 180, 200},
    {128, 128, 0, 100, 0, 180, 180, 180, 200},
    {150, 200, 200, 200},
    {150, 200, 200, 200},
    {150, 200, 200, 200},
    120, true,
    0, false
  },

  // 3: Rehearsal standard (warm, cozy)
  {
    "Rehearsal Std",
    {128, 128, 0, 80, 0, 255, 80, 0, 180},
    {128, 128, 0, 80, 0, 255, 80, 0, 180},
    {180, 255, 120, 40},
    {180, 255, 120, 40},
    {180, 255, 120, 40},
    150, true,
    0, false
  },

  // 4: Rehearsal focus (Picos as spot, couch subtle)
  {
    "Rehearsal Focus",
    {128, 100, 0, 200, 0, 0, 0, 0, 255},
    {128, 100, 0, 200, 0, 0, 0, 0, 255},
    {80, 255, 180, 100},
    {80, 255, 180, 100},
    {80, 255, 180, 100},
    80, true,
    0, false
  },

  // === MOOD SCENES ===

  // 5: Chill blue (Couch warm as contrast)
  {
    "Chill Blue",
    {128, 128, 0, 120, 0, 0, 0, 255, 0},
    {128, 128, 0, 120, 0, 0, 0, 255, 0},
    {200, 0, 50, 255},
    {200, 0, 50, 255},
    {200, 0, 50, 255},
    100, true,
    0, false
  },

  // 6: Warm red/orange (Couch matches)
  {
    "Warm Red",
    {128, 128, 0, 150, 0, 255, 60, 0, 0},
    {128, 128, 0, 150, 0, 255, 60, 0, 0},
    {220, 255, 80, 0},
    {220, 255, 80, 0},
    {220, 255, 80, 0},
    180, true,
    0, false
  },

  // 7: Green nature
  {
    "Green Nature",
    {128, 128, 0, 130, 0, 40, 255, 0, 0},
    {128, 128, 0, 130, 0, 40, 255, 0, 0},
    {200, 30, 255, 30},
    {200, 30, 255, 30},
    {200, 30, 255, 30},
    60, true,
    0, false
  },

  // 8: Purple haze
  {
    "Purple Haze",
    {128, 128, 0, 180, 0, 200, 0, 255, 0},
    {128, 128, 0, 180, 0, 200, 0, 255, 0},
    {220, 180, 0, 255},
    {220, 180, 0, 255},
    {220, 180, 0, 255},
    40, true,
    0, false
  },

  // 9: UV party (Couch off for UV effect)
  {
    "UV Party",
    {128, 128, 0, 100, 0, 80, 0, 200, 0},
    {128, 128, 0, 100, 0, 80, 0, 200, 0},
    {150, 100, 0, 200},
    {150, 100, 0, 200},
    {150, 100, 0, 200},
    0, true,
    255, false
  },

  // === SHOW SCENES ===

  // 10: Show red-blue split
  {
    "Show Split",
    {64, 128, 0, 255, 0, 255, 0, 0, 0},
    {192, 128, 0, 255, 0, 0, 0, 255, 0},
    {255, 255, 0, 0},
    {255, 0, 0, 255},
    {255, 255, 0, 0},
    0, true,
    0, false
  },

  // 11: Show cyan/magenta
  {
    "Show Cyan Mag",
    {100, 80, 0, 255, 0, 255, 0, 255, 0},
    {156, 80, 0, 255, 0, 0, 255, 255, 0},
    {255, 255, 0, 255},
    {255, 0, 255, 255},
    {255, 255, 0, 255},
    0, true,
    0, false
  },

  // 12: Show full white
  {
    "Show Full White",
    {128, 128, 0, 255, 0, 255, 255, 255, 255},
    {128, 128, 0, 255, 0, 255, 255, 255, 255},
    {255, 255, 255, 255},
    {255, 255, 255, 255},
    {255, 255, 255, 255},
    255, true,
    0, false
  },

  // 13: Show strobe (subtle)
  {
    "Show Strobe",
    {128, 128, 0, 255, 80, 255, 255, 255, 255},
    {128, 128, 0, 255, 80, 255, 255, 255, 255},
    {255, 255, 255, 255},
    {255, 255, 255, 255},
    {255, 255, 255, 255},
    0, true,
    0, false
  },

  // 14: Show cross (Picos crossed)
  {
    "Show Cross",
    {192, 100, 0, 255, 0, 255, 100, 0, 0},
    {64, 100, 0, 255, 0, 0, 100, 255, 0},
    {200, 255, 100, 0},
    {200, 0, 100, 255},
    {200, 255, 100, 0},
    0, true,
    0, false
  },

  // 15: Show rainbow bars (different colors)
  {
    "Show Rainbow",
    {128, 128, 0, 200, 0, 255, 0, 0, 0},
    {128, 128, 0, 200, 0, 0, 0, 255, 0},
    {255, 255, 0, 0},
    {255, 0, 255, 0},
    {255, 0, 0, 255},
    0, true,
    0, false
  },

  // 16: Show yellow power
  {
    "Show Yellow",
    {128, 90, 0, 255, 0, 255, 200, 0, 0},
    {128, 90, 0, 255, 0, 255, 200, 0, 0},
    {255, 255, 200, 0},
    {255, 255, 200, 0},
    {255, 255, 200, 0},
    0, true,
    0, false
  },

  // 17: Show sweep position (Picos outward)
  {
    "Show Wide",
    {40, 128, 0, 255, 0, 255, 0, 100, 0},
    {215, 128, 0, 255, 0, 255, 0, 100, 0},
    {200, 255, 0, 100},
    {200, 255, 0, 100},
    {200, 255, 0, 100},
    0, true,
    0, false
  },

  // 18: Show floor (Picos downward)
  {
    "Show Floor",
    {128, 200, 0, 255, 0, 0, 200, 255, 0},
    {128, 200, 0, 255, 0, 0, 200, 255, 0},
    {255, 0, 200, 255},
    {255, 0, 200, 255},
    {255, 0, 200, 255},
    0, true,
    0, false
  },

  // 19: Lounge (only couch lamp + subtle bars)
  {
    "Lounge",
    PICO_OFF, PICO_OFF,
    {100, 255, 100, 50},
    {100, 255, 100, 50},
    {100, 255, 100, 50},
    255, true,
    0, false
  }
};

// === FUNCTIONS ===

// Linear interpolation between two byte values
byte lerpByte(byte from, byte to, byte step, byte totalSteps) {
  if (step >= totalSteps) return to;
  int delta = (int)to - (int)from;
  return from + ((delta * step) / totalSteps);
}

// Interpolate between two PicoBeam states
PicoBeamState lerpPicoBeam(const PicoBeamState& from, const PicoBeamState& to, byte step, byte totalSteps) {
  PicoBeamState result;
  result.pan = lerpByte(from.pan, to.pan, step, totalSteps);
  result.tilt = lerpByte(from.tilt, to.tilt, step, totalSteps);
  result.speed = lerpByte(from.speed, to.speed, step, totalSteps);
  result.dimmer = lerpByte(from.dimmer, to.dimmer, step, totalSteps);
  result.strobe = lerpByte(from.strobe, to.strobe, step, totalSteps);
  result.red = lerpByte(from.red, to.red, step, totalSteps);
  result.green = lerpByte(from.green, to.green, step, totalSteps);
  result.blue = lerpByte(from.blue, to.blue, step, totalSteps);
  result.white = lerpByte(from.white, to.white, step, totalSteps);
  return result;
}

// Interpolate between two LED Bar states
LedBarState lerpLedBar(const LedBarState& from, const LedBarState& to, byte step, byte totalSteps) {
  LedBarState result;
  result.dimmer = lerpByte(from.dimmer, to.dimmer, step, totalSteps);
  result.red = lerpByte(from.red, to.red, step, totalSteps);
  result.green = lerpByte(from.green, to.green, step, totalSteps);
  result.blue = lerpByte(from.blue, to.blue, step, totalSteps);
  return result;
}

// Save current scene to EEPROM
void saveSceneToEEPROM() {
  EEPROM.update(EEPROM_ADDR_SCENE, currentScene);
  EEPROM.update(EEPROM_ADDR_MAGIC, EEPROM_MAGIC);
}

// Load scene from EEPROM (if valid)
void loadSceneFromEEPROM() {
  byte magic = EEPROM.read(EEPROM_ADDR_MAGIC);
  if (magic == EEPROM_MAGIC) {
    byte savedScene = EEPROM.read(EEPROM_ADDR_SCENE);
    if (savedScene < SCENE_COUNT) {
      currentScene = savedScene;
      previousScene = savedScene;
    }
  }
}

void setup() {
  DMXSerial.init(DMXController);

  // Initialize display (default I2C address 0x70)
  display.begin(0x70);
  display.setBrightness(5);  // 0-15, not too bright

  pinMode(PIN_MASTER, INPUT_PULLUP);
  pinMode(PIN_PREV, INPUT_PULLUP);
  pinMode(PIN_NEXT, INPUT_PULLUP);

  // Load last scene from EEPROM
  loadSceneFromEEPROM();

  // Set all channels to 0
  for (int i = 1; i <= TOTAL_CHANNELS; i++) {
    DMXSerial.write(i, 0);
  }

  // Initial display
  updateDisplay();
}

void loop() {
  // Read master switch
  bool newMasterState = (digitalRead(PIN_MASTER) == LOW);

  if (newMasterState != masterOn) {
    masterOn = newMasterState;
    outputSceneWithFade();
    updateDisplay();
    delay(50);
  }

  // Read buttons
  if (buttonPressed(PIN_NEXT)) {
    previousScene = currentScene;
    currentScene = (currentScene + 1) % SCENE_COUNT;
    saveSceneToEEPROM();
    updateDisplay();
    if (masterOn) outputSceneWithFade();
  }

  if (buttonPressed(PIN_PREV)) {
    previousScene = currentScene;
    currentScene = (currentScene + SCENE_COUNT - 1) % SCENE_COUNT;
    saveSceneToEEPROM();
    updateDisplay();
    if (masterOn) outputSceneWithFade();
  }
}

bool buttonPressed(byte pin) {
  if (digitalRead(pin) == LOW) {
    delay(50);  // Debounce
    while (digitalRead(pin) == LOW);  // Wait until released
    delay(50);
    return true;
  }
  return false;
}

void updateDisplay() {
  display.clear();

  if (!masterOn) {
    // Display "OFF"
    display.writeDigitRaw(0, 0x00);        // empty
    display.writeDigitRaw(1, 0x3F);        // O
    display.writeDigitRaw(3, 0x71);        // F
    display.writeDigitRaw(4, 0x71);        // F
  } else {
    // Display "P.XX" (P + preset number)
    display.writeDigitRaw(0, 0x73);        // P
    display.writeDigitNum(1, currentScene / 10, false);
    display.writeDigitNum(3, currentScene % 10, false);
    display.writeDigitRaw(4, 0x00);        // empty
  }

  display.writeDisplay();
}

void outputSceneWithFade() {
  if (!masterOn) {
    // Blackout - fade to black
    Scene currentSceneData;
    memcpy_P(&currentSceneData, &scenes[previousScene], sizeof(Scene));

    Scene blackScene;
    memcpy_P(&blackScene, &scenes[0], sizeof(Scene));  // Scene 0 is blackout

    fadeToScene(currentSceneData, blackScene);
    return;
  }

  // Read previous and current scenes from PROGMEM
  Scene fromScene;
  Scene toScene;
  memcpy_P(&fromScene, &scenes[previousScene], sizeof(Scene));
  memcpy_P(&toScene, &scenes[currentScene], sizeof(Scene));

  fadeToScene(fromScene, toScene);
}

void fadeToScene(const Scene& from, const Scene& to) {
  // Set non-fading fixtures instantly before the fade loop
  if (!to.uvFade) {
    DMXSerial.write(BOTEX_UV, to.uvLight);
  }
  if (!to.couchFade) {
    DMXSerial.write(BOTEX_COUCH, to.couchLight);
  }

  for (byte step = 0; step <= FADE_STEPS; step++) {
    // Interpolate PicoBeams (always fade)
    PicoBeamState pico1 = lerpPicoBeam(from.pico1, to.pico1, step, FADE_STEPS);
    PicoBeamState pico2 = lerpPicoBeam(from.pico2, to.pico2, step, FADE_STEPS);

    // Interpolate LED Bars (always fade)
    LedBarState bar1 = lerpLedBar(from.bar1, to.bar1, step, FADE_STEPS);
    LedBarState bar2 = lerpLedBar(from.bar2, to.bar2, step, FADE_STEPS);
    LedBarState bar3 = lerpLedBar(from.bar3, to.bar3, step, FADE_STEPS);

    // Output interpolated values
    outputPicoBeam(PICO1_START, pico1);
    outputPicoBeam(PICO2_START, pico2);
    outputLedBar(BAR1_START, bar1);
    outputLedBar(BAR2_START, bar2);
    outputLedBar(BAR3_START, bar3);

    // Output fading fixtures only if they should fade
    if (to.couchFade) {
      byte couchLight = lerpByte(from.couchLight, to.couchLight, step, FADE_STEPS);
      DMXSerial.write(BOTEX_COUCH, couchLight);
    }
    if (to.uvFade) {
      byte uvLight = lerpByte(from.uvLight, to.uvLight, step, FADE_STEPS);
      DMXSerial.write(BOTEX_UV, uvLight);
    }

    // Wait before next step (except on last step)
    if (step < FADE_STEPS) {
      delay(FADE_STEP_DELAY);
    }
  }
}

void outputPicoBeam(byte startAddr, const PicoBeamState& state) {
  DMXSerial.write(startAddr + PICO_PAN, state.pan);
  DMXSerial.write(startAddr + PICO_PAN_FINE, 0);
  DMXSerial.write(startAddr + PICO_TILT, state.tilt);
  DMXSerial.write(startAddr + PICO_TILT_FINE, 0);
  DMXSerial.write(startAddr + PICO_SPEED, state.speed);
  DMXSerial.write(startAddr + PICO_DIMMER, state.dimmer);
  DMXSerial.write(startAddr + PICO_STROBE, state.strobe);
  DMXSerial.write(startAddr + PICO_RED, state.red);
  DMXSerial.write(startAddr + PICO_GREEN, state.green);
  DMXSerial.write(startAddr + PICO_BLUE, state.blue);
  DMXSerial.write(startAddr + PICO_WHITE, state.white);
  DMXSerial.write(startAddr + PICO_PROGRAM, 0);      // No auto programs
  DMXSerial.write(startAddr + PICO_PROG_SPEED, 0);
}

void outputLedBar(byte startAddr, const LedBarState& state) {
  DMXSerial.write(startAddr + BAR_DIMMER, state.dimmer);
  DMXSerial.write(startAddr + BAR_STROBE, 0);  // No strobe

  // All 4 segments same color
  // Seg 1
  DMXSerial.write(startAddr + BAR_SEG1_R, state.red);
  DMXSerial.write(startAddr + BAR_SEG1_G, state.green);
  DMXSerial.write(startAddr + BAR_SEG1_B, state.blue);
  // Seg 2
  DMXSerial.write(startAddr + BAR_SEG2_R, state.red);
  DMXSerial.write(startAddr + BAR_SEG2_G, state.green);
  DMXSerial.write(startAddr + BAR_SEG2_B, state.blue);
  // Seg 3
  DMXSerial.write(startAddr + BAR_SEG3_R, state.red);
  DMXSerial.write(startAddr + BAR_SEG3_G, state.green);
  DMXSerial.write(startAddr + BAR_SEG3_B, state.blue);
  // Seg 4 (only R in 12ch mode)
  DMXSerial.write(startAddr + BAR_SEG4_R, state.red);
}

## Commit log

2026-01-04 Translate repository from German to English
    - Translate Arduino code comments and scene names to English
    - Translate CLAUDE.md technical documentation to English
    - Create comprehensive English README.md with installation guide
    - Update license reference to GPL-3.0
2026-01-04 Add smooth fade transitions and EEPROM scene memory
    Features added:
    - Smooth 1-second fade between scenes with 50 interpolation steps
    - EEPROM persistence: restores last active scene on power-up
    - UV light snaps instantly (no fade) for better visual effect
    - Configurable fade duration and steps via constants
    Technical implementation:
    - Linear interpolation functions for all fixture types
    - EEPROM magic number validation to detect first run
    - Uses EEPROM.update() to minimize write cycles
    - Separate handling for UV light (instant) vs other fixtures (fade)
    Documentation:
    - Updated README.md and CLAUDE.md with new features
    - Marked fade and EEPROM features as implemented
    - Added technical deta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
    [proberaum_dmx.ino]
2026-01-04 Add per-fixture fade control flags for maintainability
    Changes:
    - Added `couchFade` and `uvFade` boolean flags to Scene struct
    - All 20 scenes updated with fade flags (couch=true, UV=false)
    - fadeToScene() now uses flags to determine fade behavior
    - Non-fading fixtures set instantly before fade loop
    - Fading fixtures only interpolated if flag is true
    Benefits:
    - More maintainable and explicit fade control
    - Easy to add more instant-snap fixtures in the future
    - Clear documentation in scene definitions
    - No hardcoded fixture names in fade logic
    - Updated CLAUDE.md with new struct and fade behavior
    - Updated README.md with per-fixture fade details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
    [proberaum_dmx.ino]
2026-01-04 Move Arduino sketch to proberaum_dmx folder
    Arduino IDE automatically reorganized the file structure by moving
    the .ino file into its own folder (standard Arduino convention).
    Structure change:
    - proberaum_dmx.ino → proberaum_dmx/proberaum_dmx.ino
2026-01-10 Add custom 3D-printable case design for DMX controller
    Features:
    - Two-part clamshell case (180×140×50mm)
    - Arduino UNO and DMX shield mounted side-by-side
    - Front panel: USB-C socket + DMX/PROG mode switch
    - Rear panel: 2× XLR connectors + DC power jack
    - Top panel: 7-segment display + toggle + 2 buttons
    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
    [dmx_controller_case.scad]
2026-01-10 Fix front/rear panel orientation and cutout height
    Issues fixed:
    - Front/rear panels were on long sides instead of short ends
    - Changed from X-axis (length) to Y-axis (width) orientation
    - Front panel now at Y=0, rear panel at Y=case_width
    - Fixed cutout height from case_height*0.5 to case_height/4
    - Cutouts now properly centered in wall height (12.5mm from bottom)
    - Updated all rotations from [0,90,0] to [90,0,0] for correct orientation
    - Fixed label positions to match new panel layout
    Component layout:
    - Front (Y=0): USB-C + DMX/PROG switch
    - Rear (Y=140): 2× XLR + DC jack
    - Top: Display + toggle + buttons
    [dmx_controller_case.scad]
2026-01-10 Add front/rear panel cutouts to bottom case half
    Fixed: Connectors need cutouts in both top AND bottom case halves
    - Added USB-C cutout to bottom half
    - Added slide switch cutout to bottom half
    - Added 2× XLR cutouts to bottom half
    - Added DC jack cutout to bottom half
    Now connectors span across the case split as intended.
    [dmx_controller_case.scad]
2026-01-10 Raise front/rear panel connectors to split line
    Changed connector Z position from case_height/4 (12.5mm) to case_height/2 (25mm)
    - Connectors now exactly at the split line between top/bottom
    - No interference with Arduino/shield inside (mounted at bottom)
    - Cleaner assembly with connectors spanning both halves
    - Better clearance for internal components
    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
    [dmx_controller_case.scad]
2026-01-10 Redesign case split: connectors in bottom, clean lid on top
    Major structural changes:
    - Total height increased: 50mm → 60mm
    - Bottom case: 35mm tall (contains all connectors)
    - Top case: 25mm tall (clean lid with only top panel cutouts)
    - Connectors now at 17.5mm height (centered in bottom case walls)
    ✅ All connectors mount entirely in bottom case
    ✅ Top case is clean lid that sits on top
    ✅ Clear rim at top of bottom case (no split through connectors)
    ✅ Case held together by screw posts, not connectors
    ✅ Much easier assembly and disassembly
    ✅ No interference with Arduino/shield inside
    - New parameters: case_bottom_height (35mm), case_top_height (25mm)
    - Remo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
    [dmx_controller_case.scad]
2026-01-10 Fine-tune XLR height, remove D-notch, align PREV label
    Three refinements:
    1. Raise rear panel connectors 2mm (17.5mm → 19.5mm)
    - Accounts for DMX shield solder bumps on bottom
    - XLR and DC jack both raised to match
    2. Remove D-notch slit from XLR cutouts
    - Not needed for Neutrik D-series panel mount
    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
    [dmx_controller_case.scad]
2026-01-10 Reposition front/rear connectors and add switch labels
    1. Move XLRs to right side above DMX shield
    - xlr_pos_x: shield_pos_x + 25 (~129mm from left)
    - Aligns with shield position for proper clearance
    2. Move DC jack to left side above Arduino
    - dc_jack_pos_x: arduino_pos_x + 25 (~40mm from left)
    3. Move front USB-C to right side above shield
    - usbc_pos_x: shield_pos_x + 10 (~113mm from left)
    - No longer interferes with Arduino
    4. Move slide switch further right
    - slide_switch_pos_x: shield_pos_x + 45 (~148mm from left)
    5. Add switch position labels
    - "MODE" label above switch
    - "DMX" label left of switch
    - "PROG" label right of switch
    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
    [dmx_controller_case.scad]
2026-01-11 Add custom 3D-printable case design and Bill of Materials
    Case Design:
    - Two-part clamshell design (180×140×60mm total)
    - Bottom case (35mm): Contains all connectors
    - Front: USB-C panel mount + DMX/PROG slide switch
    - Rear: 2× XLR connectors + DC barrel jack
    - Top case (25mm): Clean lid with controls
    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
    [dmx_controller_case.scad, dmx_controller_case_bottom.stl, dmx_controller_case_top.stl]
